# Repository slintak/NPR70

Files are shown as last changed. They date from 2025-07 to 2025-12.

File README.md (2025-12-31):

# NPR70 — New Packet Radio for 70 cm Band

A complete open-source hardware and firmware project for a modern IP packet
radio modem operating on the 70 cm amateur band (420–450 MHz).  Compatible with
the NPR [New Packet Radio](https://hackaday.io/project/164092-npr-new-packet-radio),
but with custom hardware and improvements for easier DIY assembly.

## What is NPR70?

**NPR70** is an open-source implementation of a New Packet Radio (NPR) modem — a
  protocol and hardware design for transmitting IP packets over UHF (70 cm)
  amateur radio, with the following goals:

- High throughput (typically 50–500 kbps gross rate)
- Reliable point-to-multipoint IP networking (TCP/IP, UDP, etc.)
- Fully open hardware and software
- Minimal latency and straightforward configuration

This project is **primarily for amateur radio operators** interested in building
and experimenting with modern digital data networks, Hamnet, telemetry, or
similar applications on the UHF band.

It is a fork/derivative of the
[original NPR project by F4HDK](https://hackaday.io/project/164092-npr-new-packet-radio),
but with new custom hardware, simplified design, and refactored/cleaned firmware.

## Who is this for?

- Licensed amateur radio operators interested in high-speed IP digital modes
- Hamnet and HSMM enthusiasts
- Anyone interested in open hardware wireless networking on UHF

## Hardware Overview

- **MCU**: STM32 microcontroller (STM32L432KCU, as in original)
- **RF Module**: NiceRF module for 70 cm UHF band  (based on SI4463)
- **Ethernet**: W5500 (SPI, 10/100 Mbps Ethernet controller)
- **Form Factor**: Two layer 69×100 mm PCB
- **Other**: 0402 SMD passives, SMA, Ethernet and USB-C connectors, etc.

The hardware is designed to be compact and affordable, with a focus on
DIY manufacturing and community development. All schematics and layout
files are in the [`pcb/`](pcb/) directory.

## Firmware Details

- Based on **MbedOS 5.6.6** (last version compatible with the original code)
- Derived from the [F4HDK NPR firmware]
  (https://github.com/f4hdk/NewPacketRadio), but refactored and cleaned up for
  different pinout
- Supports all main NPR features (TDMA master/slave, 2GFSK/4GFSK,
  point-to-multipoint IP bridging)
- Compatible with official NPR protocol and other compatible modems

## Key Features

| Feature | Details |
|---|---|
| **Protocol** | NPR (custom IP radio, NOT AX.25; true L3) |
| **Topology** | Point-to-multipoint (master + up to 7 clients), TDMA |
| **Modulation** | 2GFSK / 4GFSK, up to 500 kbps gross (see protocol docs) |
| **RF Band** | 70 cm amateur band (configurable, typically 430–440 MHz) |
| **Network** | Full IP stack, transparent bridging, works with DHCP, TCP/IP, UDP, etc. |
| **Range** | Up to 300 km line-of-sight (with suitable antennas and power) |
| **Hardware** | STM32 MCU, SI4463 radio, W5500 Ethernet, all open hardware  |
| **License** | GPL v3.0 (same as original NPR project) |

## Repository Structure

- `pcb/` – KiCAD project directory (schematic and PCB layout).
- `src/` – Firmware source code, based on MbedOS (legacy version), derived and
  adapted from the original NPR project.

## Quick Start

1. **Hardware**: Manufacture or assemble the PCB found in `pcb/`. BOM and
   assembly notes are included.
2. **Firmware**:
    - For building the code by youself, you will need Debian based system and
      installed `gcc-arm-none-eabi`.
    - Build firmware by running `make` in the `src/` directory.
    - Firmware binary is in  the `src/BUILD/NPR70.hex` file
    - Flash firmware to the STM32 MCU using an SWD programmer
      `pyocd load -t stm32l432kc BUILD/NPR70.hex`
3. **Configuration**: Adjust radio parameters (frequency, bandwidth,
   master/client mode, IP addresses) as described in the
   [original NPR documentation](https://cdn.hackaday.io/files/1640927020512128/NPR70_introduction_EN_v3.6.pdf)
4. **Connect**: Plug in Ethernet and power, connect antenna, and start experimenting

Basic settings to check (more details in the original NPR documentation):

* `display config`: show current configuration
* `set <param> <value>`: store value to the given parameter
* `save`: saves current configuration into the EEPROM
* `radio on`/`radio off`: turn RF on or off
* `reboot`: reboot the FW

You have to set your callsign, frequency and modulation. Rest of the parameters
is up to you and your setup.

```
set callsign AB1CDE
set frequency 434.200
set modulation 22
```

## Documentation and References

- [Original NPR project by F4HDK](https://hackaday.io/project/164092-npr-new-packet-radio)
- [Official NPR documentation (PDFs, guides, protocol)](https://cdn.hackaday.io/files/1640927020512128/NPR70_introduction_EN_v3.6.pdf)
- [Project homepage and build log (in Czech)](https://uart.cz/2773/the-new-packet-radio/)

## License

This project is released under the **GPL v3.0 license**, same as the original
NPR project by F4HDK. See [LICENSE](LICENSE) for full details.

## Contributing

Contributions are welcome! You can:

- Submit hardware design improvements (new PCB revisions, bugfixes)
- Help with firmware optimization, porting to newer MbedOS versions, or adding
  features
- Share test results, deployment reports, and real-world feedback
- Translate documentation

For major changes, please open an issue first to discuss what you would like to
change.

If you have questions or suggestions, feel free to open an
[issue](https://github.com/slintak/NPR70/issues).

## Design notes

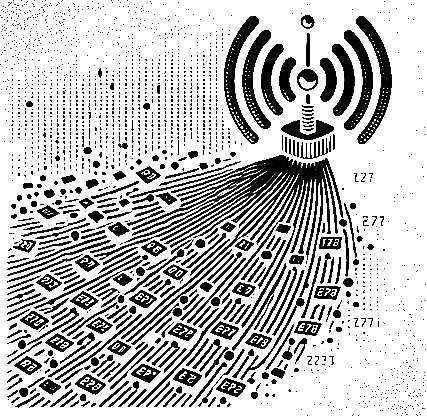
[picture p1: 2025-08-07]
pcb/imgs/art_packets_antenna.png

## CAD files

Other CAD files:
tools/radio_config_generation_2/radio_config_generation.obj

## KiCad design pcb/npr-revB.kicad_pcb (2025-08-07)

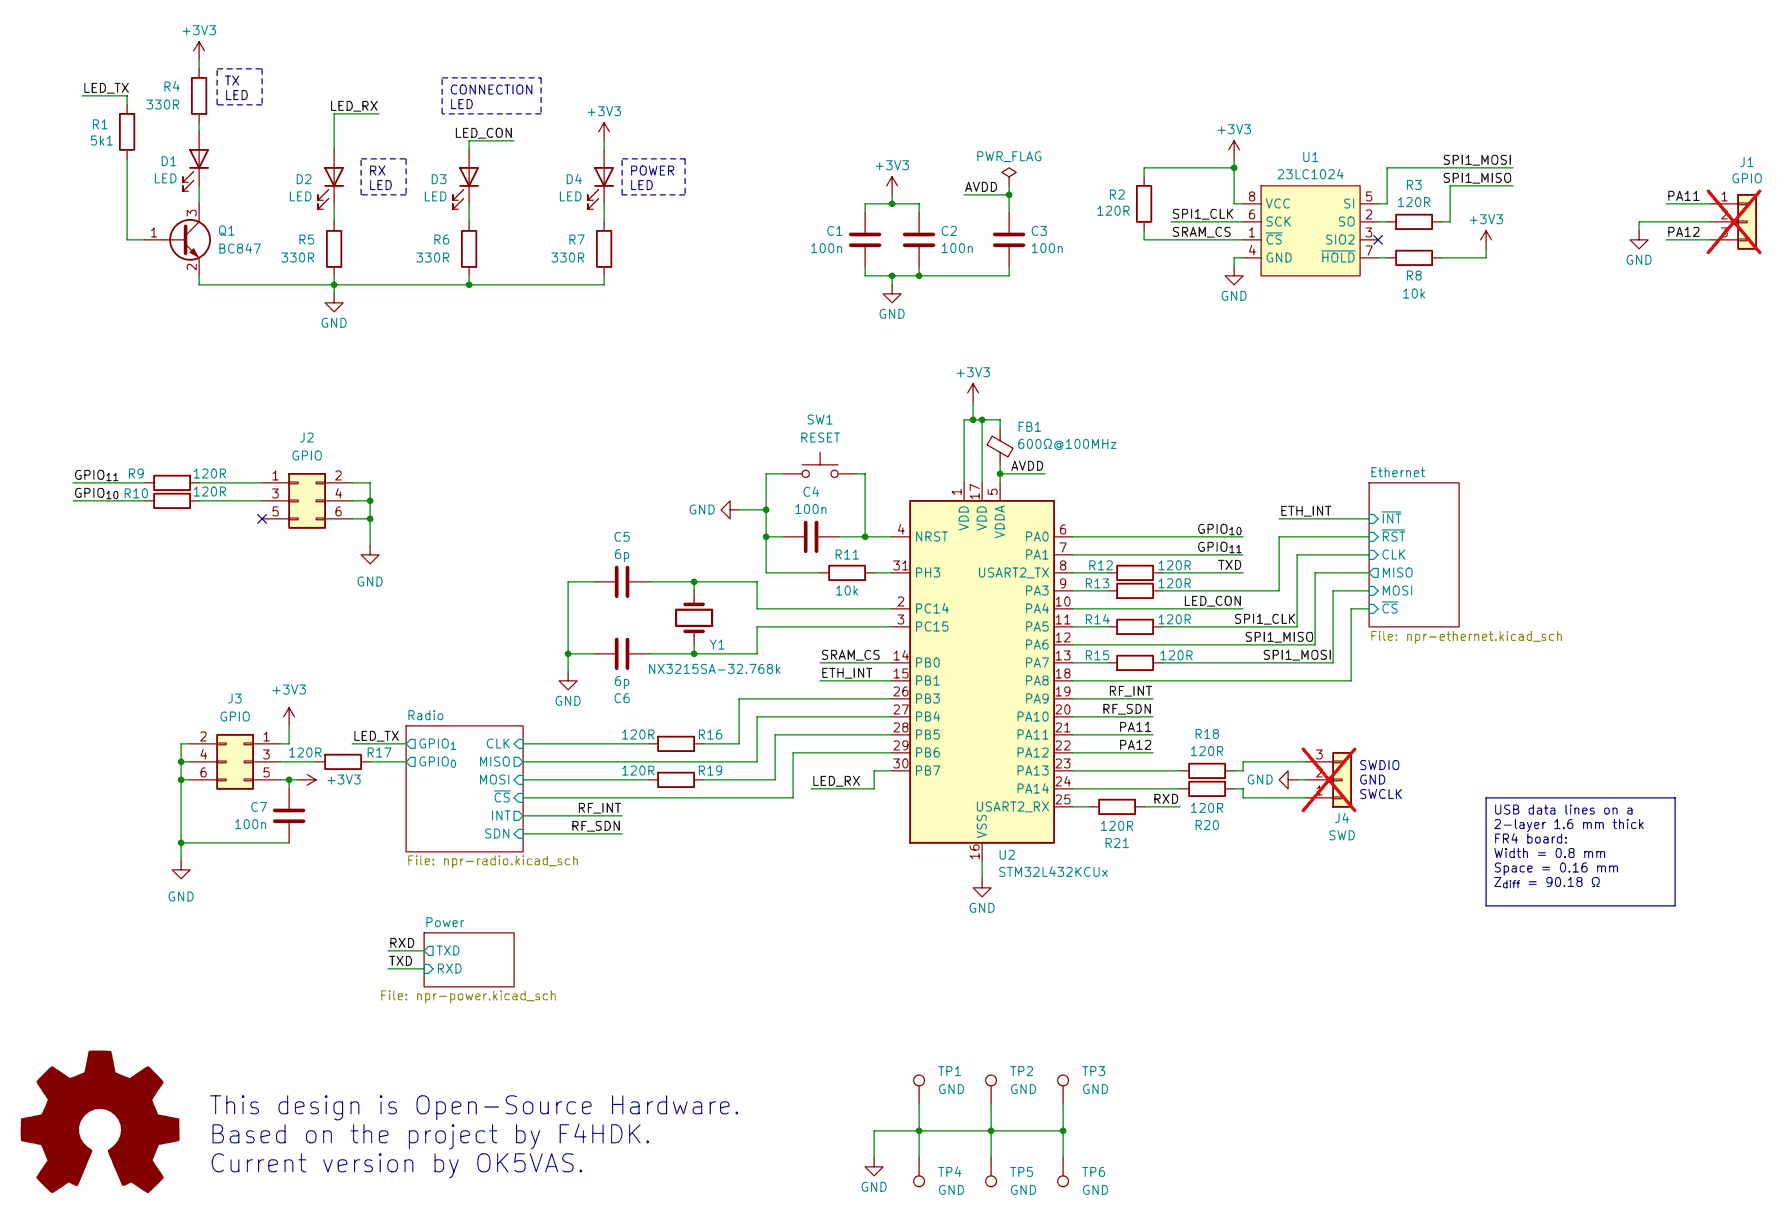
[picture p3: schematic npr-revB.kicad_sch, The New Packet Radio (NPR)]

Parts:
C1, C2, C3, C4, C7: 100n; C_0402_1005Metric; LCSC C1525
C5, C6: 6p; C_0402_1005Metric; LCSC C700515
D1, D2, D3, D4: LED; LED_0603_1608Metric; LCSC C2286
FB1: 600Ω@100MHz; L_0603_1608Metric; LCSC C19330
J1: GPIO; PinHeader_1x03_P2.54mm_Vertical; not fitted
J2, J3: GPIO; IDC-Header_2x03_P2.54mm_Horizontal; LCSC C34945
J4: SWD; PinHeader_1x03_P2.54mm_Vertical; not fitted
Q1: BC847; SOT-23; LCSC C57668
R1: 5k1; R_0402_1005Metric; LCSC C25905
R2, R3, R9, R10, R12, R13, R14, R15, R16, R17, R18, R19, R20, R21: 120R; R_0402_1005Metric; LCSC C25079
R4, R5, R6, R7: 330R; R_0402_1005Metric; LCSC C12246
R8, R11: 10k; R_0402_1005Metric; LCSC C25744
SW1: RESET; SW_SPST_CK_RS282G05A3; LCSC C483808
TP1, TP2, TP3, TP4, TP5, TP6: GND; TestPoint_Pad_D3.0mm
U1: 23LC1024; SOP-8_3.9x4.9mm_P1.27mm; LCSC C48388
U2: STM32L432KCUx; QFN-32-1EP_5x5mm_P0.5mm_EP3.45x3.45mm; LCSC C1337280
Y1: NX3215SA-32.768k; Crystal_SMD_3215-2Pin_3.2x1.5mm; LCSC C156244

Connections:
+3V3: C1.1, C2.1, C7.1, D4.2 (A), FB1.1, J3.1, J3.5, R2.2, R4.1, R8.2, U1.8 (VCC), U2.1 (VDD), U2.17 (VDD); also elsewhere on the board
/AVDD: C3.1, FB1.2, U2.5 (VDDA)
/ETH_INT: U2.15 (PB1); also elsewhere on the board
/Ethernet/~CS: U2.18 (PA8); also elsewhere on the board
/Ethernet/~RST: R13.1; also elsewhere on the board
/GPIO_{10}: R10.1, U2.6 (PA0)
/GPIO_{11}: R9.1, U2.7 (PA1)
/LED_CON: D3.2 (A), U2.10 (PA4)
/LED_RX: D2.2 (A), U2.30 (PB7)
/LED_TX: R1.2; also elsewhere on the board
/PA11: J1.1, U2.21 (PA11)
/PA12: J1.3, U2.22 (PA12)
/RF_INT: U2.19 (PA9); also elsewhere on the board
/RF_SDN: U2.20 (PA10); also elsewhere on the board
/RXD: R21.2; also elsewhere on the board
/Radio/CLK: R16.2; also elsewhere on the board
/Radio/GPIO_{0}: R17.1; also elsewhere on the board
/Radio/MISO: U2.27 (PB4); also elsewhere on the board
/Radio/MOSI: R19.2; also elsewhere on the board
/Radio/~CS: U2.29 (PB6); also elsewhere on the board
/SPI1_CLK: R14.1, U1.6 (SCK); also elsewhere on the board
/SPI1_MISO: R3.1, U2.12 (PA6); also elsewhere on the board
/SPI1_MOSI: R15.1, U1.5 (SI); also elsewhere on the board
/SRAM_CS: R2.1, U1.1 (~CS), U2.14 (PB0)
/TXD: R12.2; also elsewhere on the board
GND: C1.2, C2.2, C3.2, C4.1, C5.1, C6.1, C7.2, J1.2, J2.2, J2.4, J2.6, J3.2, J3.4, J3.6, J4.2, Q1.2 (E), R5.2, R6.2, R7.2, R11.1, SW1.1, TP1.1, TP2.1, TP3.1, TP4.1, TP5.1, TP6.1, U1.4 (GND), U2.16 (VSS), U2.32 (VSS), U2.33 (VSS); also elsewhere on the board
unnamed: D1.2 (A), R4.2
unnamed: D1.1 (K), Q1.3 (C)
unnamed: D2.1 (K), R5.1
unnamed: D3.1 (K), R6.1
unnamed: D4.1 (K), R7.1
unnamed: J2.1, R9.2
unnamed: J2.3, R10.2
unnamed: J3.3, R17.2
unnamed: J4.1, R20.2
unnamed: J4.3, R18.2
unnamed: Q1.1 (B), R1.1
unnamed: R3.2, U1.2 (SO)
unnamed: R8.1, U1.7 (~HOLD)
unnamed: C4.2, SW1.2, U2.4 (NRST)
unnamed: R12.1, U2.8 (USART2_TX)
unnamed: R13.2, U2.9 (PA3)
unnamed: R14.2, U2.11 (PA5)
unnamed: R15.2, U2.13 (PA7)
unnamed: R18.1, U2.23 (PA13)
unnamed: R20.1, U2.24 (PA14)
unnamed: R21.1, U2.25 (USART2_RX)
unnamed: R16.1, U2.26 (PB3)
unnamed: R19.1, U2.28 (PB5)
unnamed: C5.2, U2.2 (PC14), Y1.2
unnamed: C6.2, U2.3 (PC15), Y1.1
unnamed: R11.2, U2.31 (PH3)

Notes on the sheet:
This design is Open-Source Hardware. Based on the project by F4HDK. Current version by OK5VAS.
SWDIO GND SWCLK
RX LED
CONNECTION LED
TX LED
POWER LED
USB data lines on a 2-layer 1.6 mm thick FR4 board: Width = 0.8 mm Space = 0.16 mm Z_{diff} = 90.18 Ω

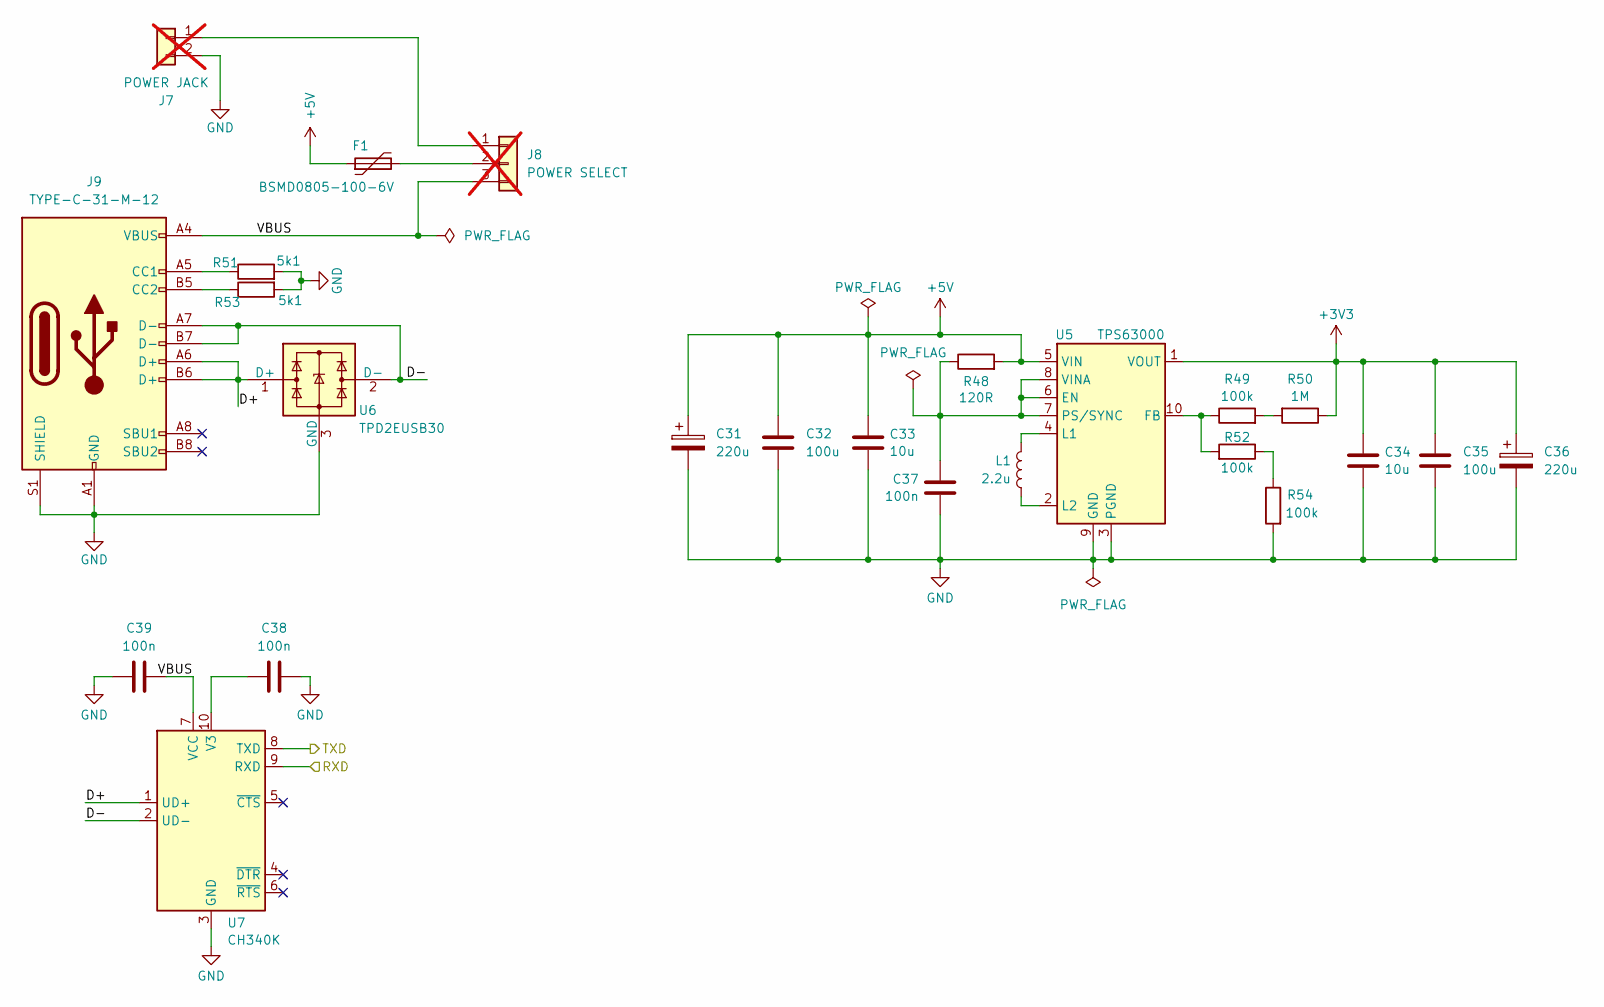
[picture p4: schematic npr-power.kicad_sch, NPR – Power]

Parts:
C31, C36: 220u; CP_Elec_6.3x5.4; LCSC C2833309
C32, C35: 100u; C_1206_3216Metric; LCSC C15008
C33, C34: 10u; C_0603_1608Metric; LCSC C19702
C37, C38, C39: 100n; C_0402_1005Metric; LCSC C1525
F1: BSMD0805-100-6V; Fuse_0805_2012Metric; LCSC C883112
J7: POWER JACK; PinHeader_1x02_P2.54mm_Vertical; not fitted
J8: POWER SELECT; PinHeader_1x03_P2.54mm_Vertical; not fitted
J9: TYPE-C-31-M-12; USB_C_Receptacle_HRO_TYPE-C-31-M-12; LCSC C165948
L1: 2.2u; L_Taiyo-Yuden_MD-3030; LCSC C5159665
R48: 120R; R_0402_1005Metric; LCSC C25079
R49, R52, R54: 100k; R_0402_1005Metric; LCSC C25741
R50: 1M; R_0402_1005Metric; LCSC C26083
R51, R53: 5k1; R_0402_1005Metric; LCSC C25905
U5: TPS63000; Texas_DRC0010J_ThermalVias; LCSC C24966
U6: TPD2EUSB30; Texas_DRT-3; LCSC C97502
U7: CH340K; SSOP-10-1EP_3.9x4.9mm_P1mm_EP2.1x3.3mm; LCSC C18208922

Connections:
+3V3: C34.1, C35.1, C36.1, R50.1, U5.1 (VOUT); also elsewhere on the board
+5V: C31.1, C32.1, C33.1, F1.1, R48.2, U5.5 (VIN); also elsewhere on the board
/Power/D+: J9.A6 (D+), J9.B6 (D+), U6.1 (D+), U7.1 (UD+)
/Power/D-: J9.A7 (D-), J9.B7 (D-), U6.2 (D-), U7.2 (UD-)
/Power/VBUS: C39.2, J8.3, J9.A4 (VBUS), J9.A9 (VBUS), J9.B4 (VBUS), J9.B9 (VBUS), U7.7 (VCC)
/RXD: U7.8 (TXD); also elsewhere on the board
/TXD: U7.9 (RXD); also elsewhere on the board
GND: C31.2, C32.2, C33.2, C34.2, C35.2, C36.2, C37.2, C38.2, C39.1, J7.2, J9.A1 (GND), J9.A12 (GND), J9.B1 (GND), J9.B12 (GND), J9.S1 (SHIELD), R51.2, R53.2, R54.2, U5.3 (PGND), U5.9 (GND), U5.11 (PGND), U6.3 (GND), U7.3 (GND), U7.11 (GND); also elsewhere on the board
unnamed: J7.1, J8.1
unnamed: F1.2, J8.2
unnamed: J9.A5 (CC1), R51.1
unnamed: J9.B5 (CC2), R53.1
unnamed: R49.2, R50.2
unnamed: R52.1, R54.1
unnamed: C37.1, R48.1, U5.6 (EN), U5.7 (PS/SYNC), U5.8 (VINA)
unnamed: R49.1, R52.2, U5.10 (FB)
unnamed: L1.2, U5.4 (L1)
unnamed: L1.1, U5.2 (L2)
unnamed: C38.1, U7.10 (V3)

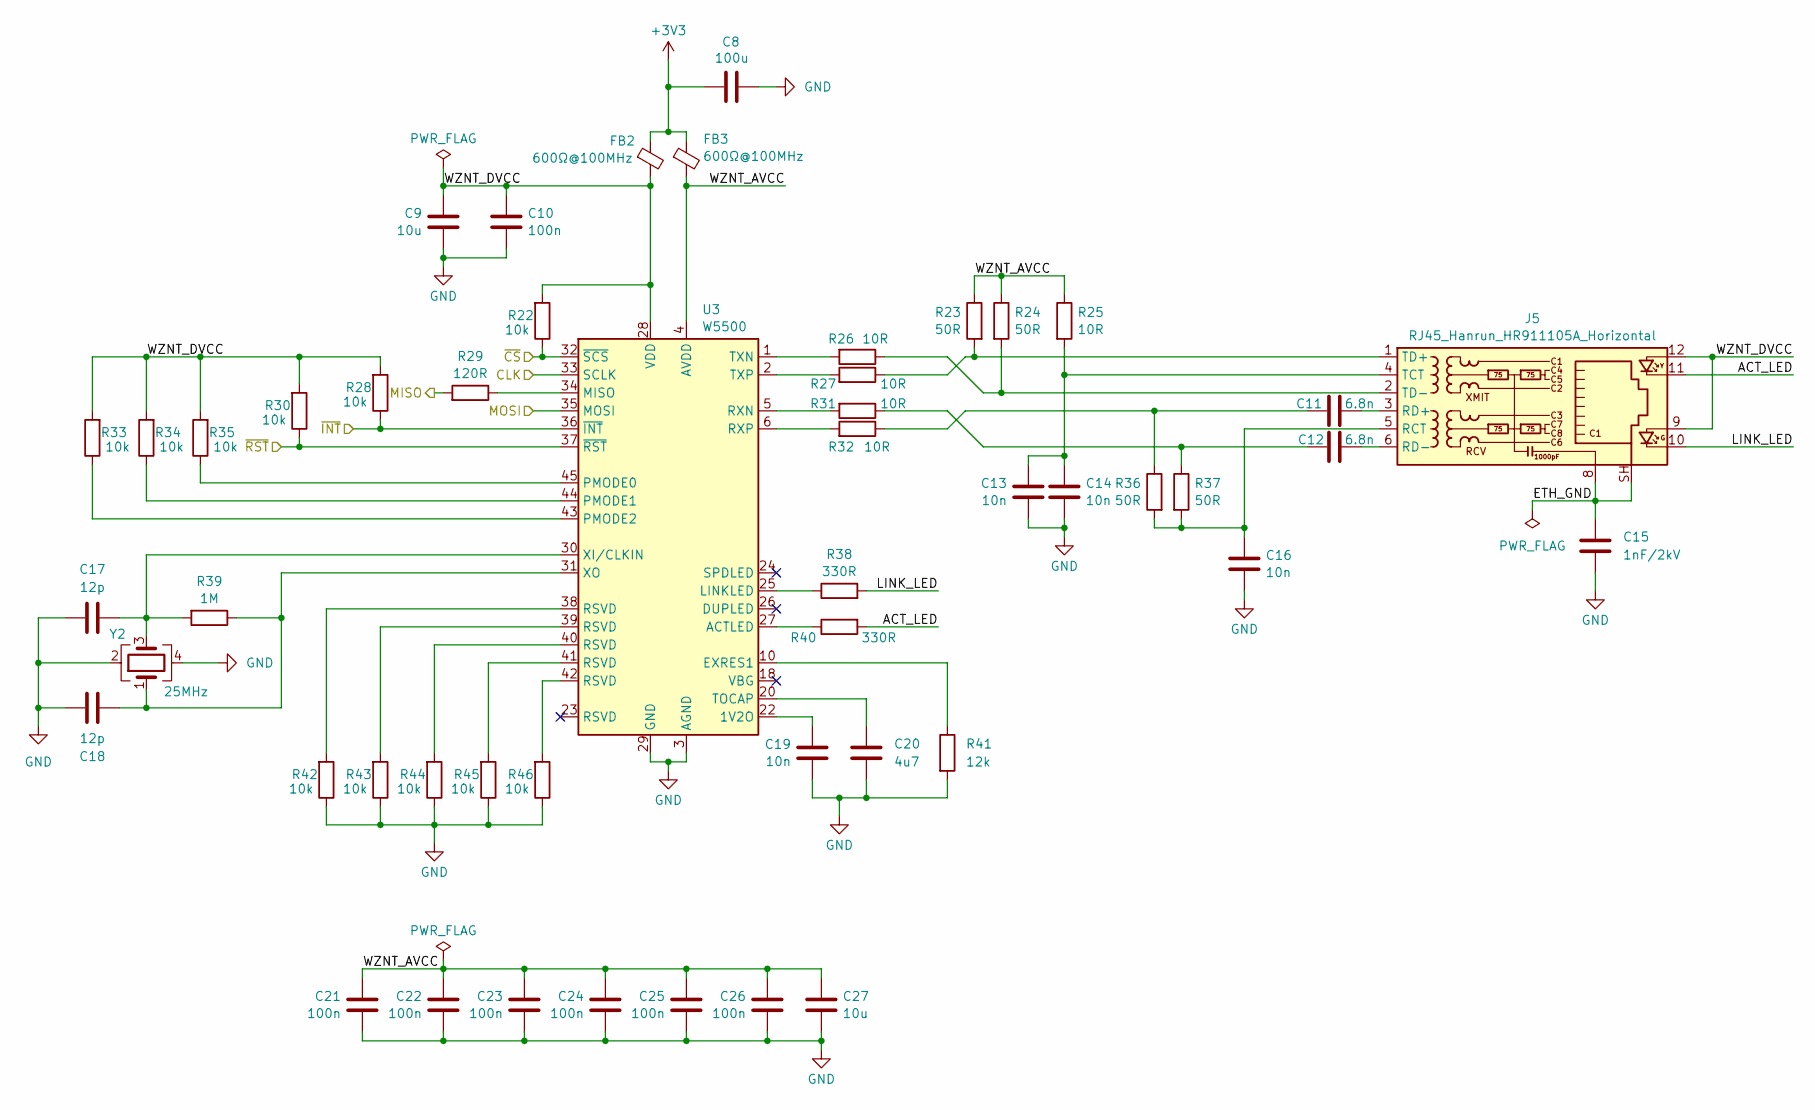
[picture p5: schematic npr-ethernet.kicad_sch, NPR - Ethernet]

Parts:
C8: 100u; C_1206_3216Metric; LCSC C15008
C9, C27: 10u; C_0402_1005Metric; LCSC C15525
C10, C21, C22, C23, C24, C25, C26: 100n; C_0402_1005Metric; LCSC C1525
C11, C12: 6.8n; C_0402_1005Metric; LCSC C93654
C13, C14, C16, C19: 10n; C_0402_1005Metric; LCSC C318577
C15: 1nF/2kV; C_1206_3216Metric; LCSC C23631
C17, C18: 12p; C_0402_1005Metric; LCSC C106201
C20: 4u7; C_0402_1005Metric; LCSC C23733
FB2, FB3: 600Ω@100MHz; L_0603_1608Metric; LCSC C19330
J5: RJ45_Hanrun_HR911105A_Horizontal; LCSC C12074
R22, R28, R30, R33, R34, R35, R42, R43, R44, R45, R46: 10k; R_0402_1005Metric; LCSC C25744
R23, R24, R36, R37: 50R; R_0402_1005Metric; LCSC C227387
R25, R26, R27, R31, R32: 10R; R_0402_1005Metric; LCSC C25139
R29: 120R; R_0402_1005Metric; LCSC C25079
R38, R40: 330R; R_0402_1005Metric; LCSC C12246
R39: 1M; R_0402_1005Metric; LCSC C26083
R41: 12k; R_0402_1005Metric; LCSC C25752
U3: W5500; LQFP-48_7x7mm_P0.5mm; LCSC C32843
Y2: 25MHz; Crystal_SMD_3225-4Pin_3.2x2.5mm; LCSC C9006

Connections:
+3V3: C8.1, FB2.1, FB3.1; also elsewhere on the board
/ETH_INT: R28.1, U3.36 (~INT); also elsewhere on the board
/Ethernet/ACT_LED: J5.11, R40.2
/Ethernet/ETH_GND: C15.1, J5.8, J5.SH
/Ethernet/LINK_LED: J5.10, R38.2
/Ethernet/WZNT_AVCC: C21.1, C22.1, C23.1, C24.1, C25.1, C26.1, C27.1, FB3.2, R23.1, R24.1, R25.1, U3.4 (AVDD), U3.8 (AVDD), U3.11 (AVDD), U3.15 (AVDD), U3.17 (AVDD), U3.21 (AVDD)
/Ethernet/WZNT_DVCC: C9.1, C10.1, FB2.2, J5.9, J5.12, R22.2, R28.2, R30.2, R33.2, R34.2, R35.2, U3.28 (VDD)
/Ethernet/~CS: R22.1, U3.32 (~SCS); also elsewhere on the board
/Ethernet/~RST: R30.1, U3.37 (~RST); also elsewhere on the board
/SPI1_CLK: U3.33 (SCLK); also elsewhere on the board
/SPI1_MISO: R29.2; also elsewhere on the board
/SPI1_MOSI: U3.35 (MOSI); also elsewhere on the board
GND: C8.2, C9.2, C10.2, C13.2, C14.2, C15.2, C16.2, C17.2, C18.2, C19.2, C20.2, C21.2, C22.2, C23.2, C24.2, C25.2, C26.2, C27.2, R41.2, R42.1, R43.1, R44.1, R45.1, R46.1, U3.3 (AGND), U3.9 (AGND), U3.14 (AGND), U3.16 (AGND), U3.19 (AGND), U3.29 (GND), U3.48 (AGND), Y2.2, Y2.4; also elsewhere on the board
unnamed: C11.2, R32.1, R36.1
unnamed: C12.2, R31.1, R37.1
unnamed: C16.1, J5.5 (RCT), R36.2, R37.2
unnamed: C11.1, J5.3 (RD+)
unnamed: C12.1, J5.6 (RD-)
unnamed: C13.1, C14.1, J5.4 (TCT), R25.2
unnamed: J5.1 (TD+), R23.2, R27.1
unnamed: J5.2 (TD-), R24.2, R26.1
unnamed: R42.2, U3.38 (RSVD)
unnamed: R43.2, U3.39 (RSVD)
unnamed: R44.2, U3.40 (RSVD)
unnamed: R45.2, U3.41 (RSVD)
unnamed: R46.2, U3.42 (RSVD)
unnamed: C19.1, U3.22 (1V2O)
unnamed: R40.1, U3.27 (ACTLED)
unnamed: R41.1, U3.10 (EXRES1)
unnamed: R38.1, U3.25 (LINKLED)
unnamed: R29.1, U3.34 (MISO)
unnamed: R35.1, U3.45 (PMODE0)
unnamed: R34.1, U3.44 (PMODE1)
unnamed: R33.1, U3.43 (PMODE2)
unnamed: R31.2, U3.5 (RXN)
unnamed: R32.2, U3.6 (RXP)
unnamed: C20.1, U3.20 (TOCAP)
unnamed: R26.2, U3.1 (TXN)
unnamed: R27.2, U3.2 (TXP)
unnamed: C17.1, R39.2, U3.30 (XI/CLKIN), Y2.3
unnamed: C18.1, R39.1, U3.31 (XO), Y2.1

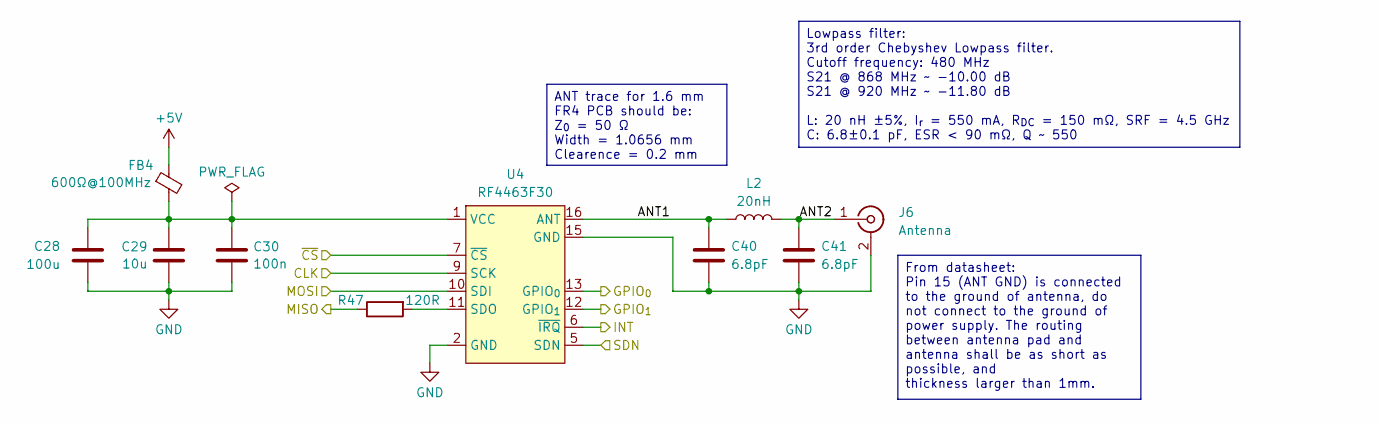
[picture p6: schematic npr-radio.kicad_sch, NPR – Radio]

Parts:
C28: 100u; C_1206_3216Metric; LCSC C15008
C29: 10u; C_0402_1005Metric; LCSC C15525
C30: 100n; C_0402_1005Metric; LCSC C1525
C40, C41: 6.8pF; C_0402_1005Metric; LCSC C88896
FB4: 600Ω@100MHz; L_0603_1608Metric; LCSC C19330
J6: Antenna; SMA_Amphenol_901-143_Horizontal; LCSC C411575
L2: 20nH; L_0603_1608Metric; LCSC C17702828
R47: 120R; R_0402_1005Metric; LCSC C25079
U4: RF4463F30; LCSC C5356658

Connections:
+5V: FB4.1; also elsewhere on the board
/LED_TX: U4.12 (GPIO_{1}); also elsewhere on the board
/RF_INT: U4.6 (~IRQ); also elsewhere on the board
/RF_SDN: U4.5 (SDN); also elsewhere on the board
/Radio/ANT1: C40.1, L2.1, U4.16 (ANT)
/Radio/ANT2: C41.1, J6.1 (In), L2.2
/Radio/CLK: U4.9 (SCK); also elsewhere on the board
/Radio/GPIO_{0}: U4.13 (GPIO_{0}); also elsewhere on the board
/Radio/MISO: R47.1; also elsewhere on the board
/Radio/MOSI: U4.10 (SDI); also elsewhere on the board
/Radio/~CS: U4.7 (~CS); also elsewhere on the board
GND: C28.2, C29.2, C30.2, C40.2, C41.2, J6.2 (Ext), U4.2 (GND), U4.8 (GND), U4.15 (GND); also elsewhere on the board
unnamed: R47.2, U4.11 (SDO)
unnamed: C28.1, C29.1, C30.1, FB4.2, U4.1 (VCC)

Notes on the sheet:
Lowpass filter: 3rd order Chebyshev Lowpass filter. Cutoff frequency: 480 MHz S21 @ 868 MHz ~ -10.00 dB S21 @ 920 MHz ~ -11.80 dB L: 20 nH ±5%, I_{r} = 550 mA, R_{DC} = 150 mΩ, SRF = 4.5 GHz C: 6.8±0.1 pF, ESR < 90 mΩ, Q ~ 550
From datasheet: Pin 15 (ANT GND) is connected to the ground of antenna, do not connect to the ground of power supply. The routing between antenna pad and antenna shall be as short as possible, and thickness larger than 1mm.
ANT trace for 1.6 mm FR4 PCB should be: Z_{0} = 50 Ω Width = 1.0656 mm Clearence = 0.2 mm

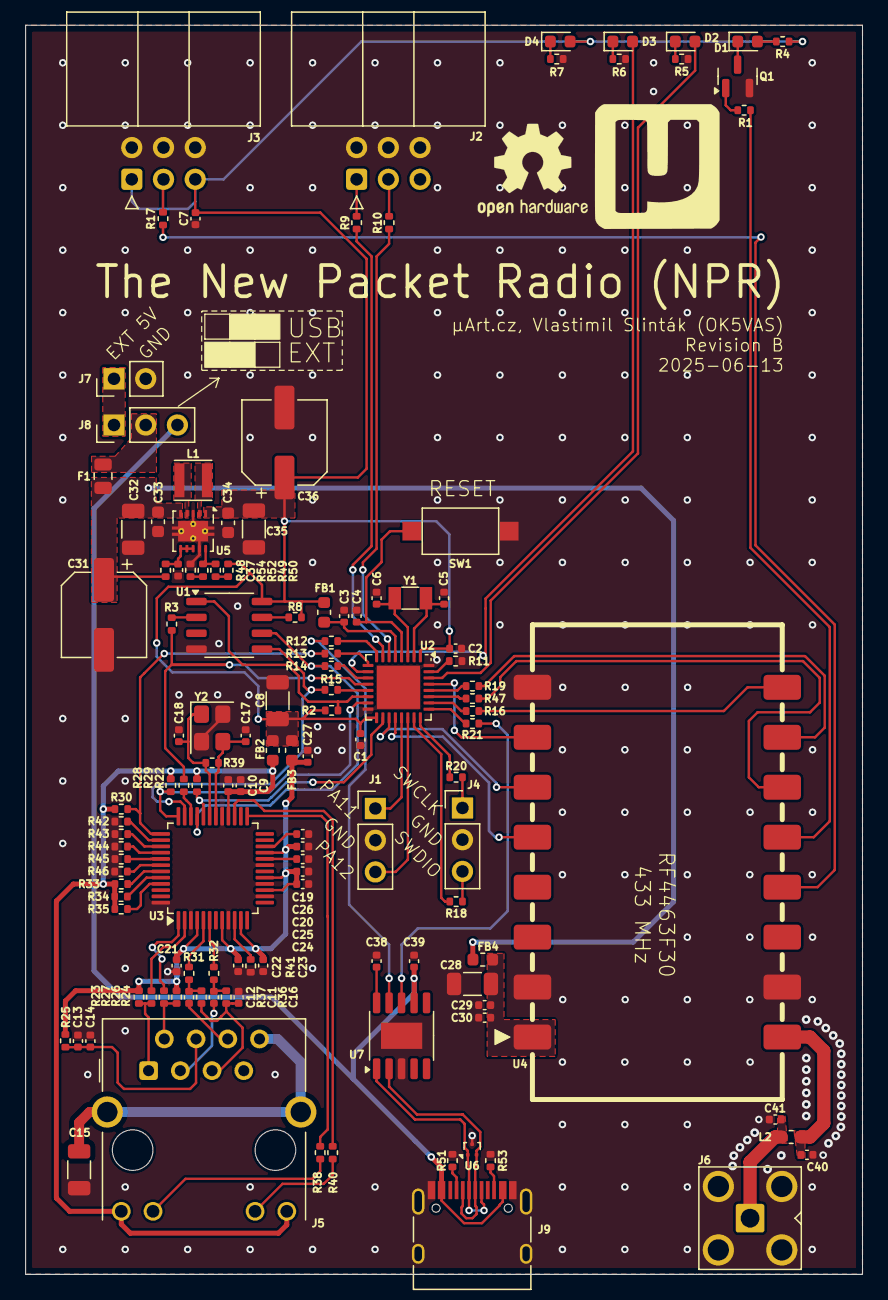
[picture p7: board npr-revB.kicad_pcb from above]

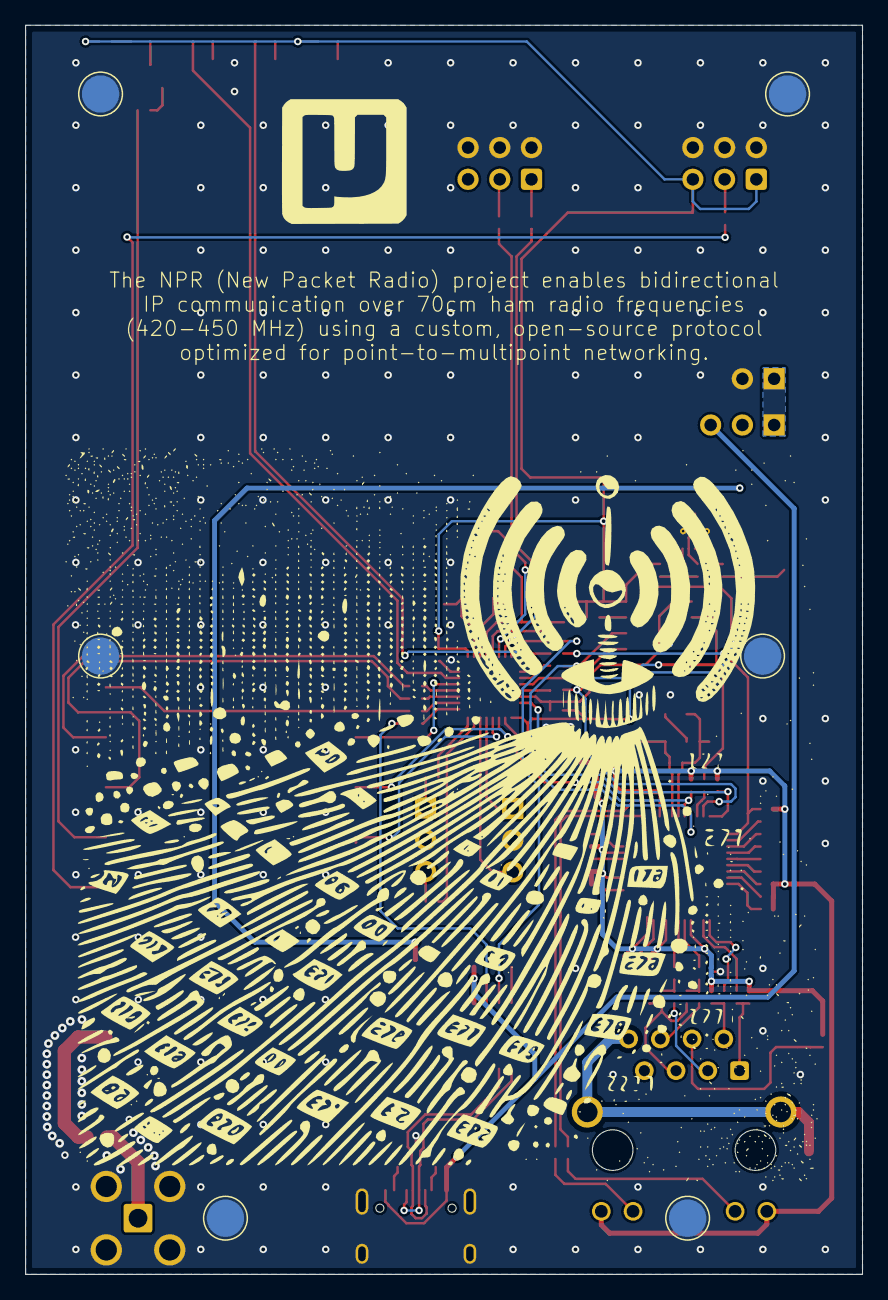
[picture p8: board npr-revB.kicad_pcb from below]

Board: 2 copper layers, 67.0 x 100.0 mm, 132 parts (6 on the bottom side), 104 nets.

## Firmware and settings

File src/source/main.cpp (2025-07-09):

// This file is part of "NPR70 modem firmware" software
// (A GMSK data modem for ham radio 430-440MHz, at several hundreds of kbps) 
// Copyright (c) 2017-2020 Guillaume F. F4HDK (amateur radio callsign)
// 
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
#include "mbed.h"
#include "W5500.h"
#include "SI4463.h"
#include "HMI_telnet.h"
//#include "Virt_Chan.h"
#include "Eth_IPv4.h"
#include "DHCP_ARP.h"
#include "global_variables.h"
#include "L1L2_radio.h"
#include "TDMA.h"
#include "signaling.h"
#include "config_flash.h"
#include "SPI_F4HDK.h"

#include "ext_SRAM2.h"

//#define NPR_L476
//Serial pc(SERIAL_TX, SERIAL_RX); // Nucleo
//Serial pc(USBTX, USBRX); //NXP LPC1769

DigitalInOut FDD_trig_pin(PA_1);//GPIO_11
InterruptIn FDD_trig_IRQ(PA_1);//GPIO_11
DigitalOut PTT_PA_pin(PA_0);//GPIO_10

DigitalOut SI4463_SDN(PA_10);

DigitalOut LED_RX_loc(PB_7);
DigitalOut LED_connected(PA_4);

DigitalIn Int_W5500(PB_1);
DigitalOut CS1(PA_8);//CS W5500
SPI_F4HDK spi_2(PA_7, PA_6, PA_5); // mosi, miso, sclk (Wiznet+SRAM)
DigitalOut CS3(PB_0);// CS ext SRAM

InterruptIn Int_SI4463(PA_9);
DigitalOut CS2(PB_6);
SPI_F4HDK spi_1(PB_5, PB_4, PB_3); // mosi, miso, sclk (radio)

int main()
{
    wait_ms(200);
    pc.baud(115200);
    pc.printf("\r\n\r\nNPR FW %s\r\n", FW_VERSION);

    Timer slow_timer;
    int i = 1;
    int temperature_timer = 0;

    static LAN_conf_T* LAN_conf_p;
    LAN_conf_p = &LAN_conf_applied;

    static W5500_chip W5500_1;
    W5500_p1 = &W5500_1;
    W5500_1.spi_port = &spi_2;
    W5500_1.cs = &CS1;
    W5500_1.interrupt = &Int_W5500;

//#ifdef EXT_SRAM_USAGE
    static ext_SRAM_chip SPI_SRAM;
    SPI_SRAM_p = &SPI_SRAM;
    SPI_SRAM.spi_port = &spi_2;
    SPI_SRAM.cs = &CS3;
//#endif

    static SI4463_Chip SI4463_1;
    SI4463_1.spi = &spi_1;//1
    SI4463_1.cs = &CS2;//2
    SI4463_1.interrupt = &Int_SI4463;
    SI4463_1.RX_LED = &LED_RX_loc;
    SI4463_1.SDN = &SI4463_SDN;

    G_SI4463 = &SI4463_1;

    G_FDD_trig_pin = &FDD_trig_pin;
    G_FDD_trig_IRQ = &FDD_trig_IRQ;
    G_PTT_PA_pin = &PTT_PA_pin;

    reset_DHCP_table(LAN_conf_p);

    spi_2.format(8,0);
    spi_1.format(8,0);
    spi_2.frequency(20000000);
    spi_1.frequency(10000000);

    for(i=0; i<radio_addr_table_size; i++) {
        CONF_radio_addr_table_status[i] = 0;
    }

    G_FDD_trig_pin->input();
    G_PTT_PA_pin->write(0);
    LED_RX_loc = 0;
    LED_connected = 0;
    CS1=1;
    CS2=1;
    CS3=1;
    SI4463_SDN = 1;

    wait_ms(20);
    is_SRAM_ext = ext_SRAM_detect();

    LED_RX_loc = 1;
    for (i=0; i<7; i++) {
        wait_ms(200);
        LED_RX_loc = !LED_RX_loc;
        LED_connected = !LED_connected;
        SI4463_SDN = !SI4463_SDN;
    }
    LED_RX_loc = 0;
    LED_connected = 0;
    SI4463_SDN = 1;

    printf("\r\n");

    RX_FIFO_WR_point = 0;
    RX_FIFO_RD_point = 0;
    RX_FIFO_last_received = 0;

    //TXPS_FIFO->is_single = 0;
    //TXPS_FIFO->WR_point = 0;
    //TXPS_FIFO->RD_point = 0;
    //TXPS_FIFO->last_ready = 0;

    GLOBAL_timer.reset();
    GLOBAL_timer.start();
    TDMA_init_all();

    //TXPS_FIFO->last_ready = TXPS_FIFO->WR_point;
    for (i=0; i<0x2000; i++) {
        RX_FIFO_data[i] = 0;
    }

    printf("      \r\n");
    for (i=0; i<radio_addr_table_size; i++) {
        CONF_radio_addr_table_IP_begin[i] = 0; // 0 = entry not active

    }
    if (is_SRAM_ext) {
        printf("config WITH ext SRAM\r\n");
    } else {
        printf("config WITHOUT ext SRAM\r\n");
    }

    wait_ms(100);
    NFPR_config_read();

    //SI4463_print_version(G_SI4463);//!!!!
    SI4463_get_state(G_SI4463);

    i = SI4463_configure_all();
    if (i == 1) {
        HMI_printf("SI4463 configured\r\n");
    } else {
        HMI_printf("SI4463 error while configure\r\n");
        SI4463_print_version(G_SI4463);
        wait_ms(5000);
        if (serial_term_loop() == 0) {//no serial char detected
            NVIC_SystemReset(); //reboot
        }
    }
    //SI4463_print_version(G_SI4463);//!!!!

    W5500_initial_configure(W5500_p1);
    wait_ms(2);
#ifdef EXT_SRAM_USAGE
    ext_SRAM_set_mode(SPI_SRAM_p);
    wait_ms(2)
    ext_SRAM_init();
#endif
    TDMA_NULL_frame_init(70);

    SI4463_periodic_temperature_check(G_SI4463);
    Int_SI4463.fall(&SI4463_HW_interrupt);
    if (CONF_radio_default_state_ON_OFF) {
        //TDMA_init_all();
        //SI4463_radio_start();
        RADIO_on(1, 0, 1);//init state, no reconfigure, HMI output
    }
    HMI_printf("ready> ");
    slow_timer.start();

    unsigned int timer_snapshot;
    int slow_action_counter = 0;
    int signaling_counter = 0;
    //SI4463_temp_check_init();

    int telnet_counter = 0;

    while(1) {
        for (i=0; i<100; i++) {
            if ( (is_TDMA_master == 1) && (CONF_master_FDD == 2) ) {
                FDDup_RX_FIFO_dequeue();
            } else {
                radio_RX_FIFO_dequeue(W5500_p1);
            }
            Eth_RX_dequeue(W5500_p1);
            TDMA_slave_timeout();
#ifdef EXT_SRAM_USAGE
            ext_SRAM_periodic_call();
#endif
            if (is_SRAM_ext == 1) {
                ext_SRAM_periodic_call();
            }
            timer_snapshot = slow_timer.read_us();
            if (timer_snapshot > 666000) {//666000
                slow_timer.reset();
                slow_action_counter++;
                if (slow_action_counter > 2) {slow_action_counter = 0; }

                if (slow_action_counter == 0) {
                    HMI_periodic_call();
                }
                //debug_counter = 0;


                if (slow_action_counter == 1) {//every 2 sec
                    signaling_counter++;
                    if (signaling_counter >= CONF_signaling_period) {
                        signaling_periodic_call();
                        signaling_counter = 0;
                    }
                }

                if (slow_action_counter == 2) {
                    DHCP_ARP_periodic_free_table();
                    W5500_re_configure_periodic_call(W5500_p1);

                    temperature_timer++;
                    if(temperature_timer > 15) {// 15 every 30 sec
                        temperature_timer = 0;
                        G_need_temperature_check = 1;
                        SI4463_periodic_temperature_check_2();//SI4463_periodic_temperature_check(G_SI4463);
                    }
                }
            }
        }

        if (is_TDMA_master) {
            if (CONF_radio_state_ON_OFF==1) {LED_connected.write((timer_snapshot >> 19) & 1);}
            else {LED_connected.write(0);}
        } else {
            if (my_client_radio_connexion_state == 2) {
                LED_connected.write(1);
            }else{
                LED_connected.write(0);
            }
        }
        if (is_telnet_active) {

            telnet_counter++;
            if (telnet_counter>10) {
                telnet_loop(W5500_p1);
                telnet_counter = 0;
            }
        }
        serial_term_loop();

        if ( (LAN_conf_applied.DHCP_server_active == 1) && (is_TDMA_master == 0) ) {
            DHCP_server(LAN_conf_p, W5500_p1);
        }
    }
}

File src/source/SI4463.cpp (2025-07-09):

// This file is part of "NPR70 modem firmware" software
// (A GMSK data modem for ham radio 430-440MHz, at several hundreds of kbps) 
// Copyright (c) 2017-2020 Guillaume F. F4HDK (amateur radio callsign)
// 
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
#include "SI4463.h"

#include "mbed.h"
#include "global_variables.h"
#include "TDMA.h"
#include "HMI_telnet.h"
#include "L1L2_radio.h"
 
#ifdef FREQ_BAND_2M
    #include "SI4463_config_20_2m.h"
    #include "SI4463_config_11_2m.h"
    #include "SI4463_config_21_2m.h"
    #include "SI4463_config_12_2m.h"
    #include "SI4463_config_22_2m.h"
    #include "SI4463_config_13_2m.h"
    #include "SI4463_config_23_2m.h"
    #include "SI4463_config_14_2m.h"
    #include "SI4463_config_24_2m.h"
#else 
    //#include "SI4463_config_10.h"
    #include "SI4463_config_20.h"
    //#include "radio_config_Si4463_20.h"
    #include "SI4463_config_11.h"
    //#include "radio_config_Si4463_11.h"
    #include "SI4463_config_21.h"
    //#include "SI4463_config_21_GMSK.h"
    //#include "radio_config_Si4463_21.h"
    #include "SI4463_config_12.h"
    #include "SI4463_config_22.h"
    //#include "radio_config_Si4463_22.h"
    #include "SI4463_config_13.h"
    //#include "radio_config_Si4463_13.h"
    #include "SI4463_config_23.h"
    //#include "radio_config_Si4463_23.h"
    #include "SI4463_config_14.h"
    #include "SI4463_config_24.h"
    //#include "radio_config_Si4463_24.h"
#endif 

//Timeout SI4463_prepa_TX_1_call;
Timeout SI4463_prepa_TX_2_call;
Timeout SI4463_1st_TX_call;
Timeout SI4463_RX_timeout_call; //2019_04_05
//Ticker SI4463_temp_check2_call;

//TX_buffer_struct* TX_buff; //data structure currently used to TX

static unsigned char SI_trash[150];
static unsigned char TX_temp_rframe[384];
static unsigned char* TX_frame_to_send;
static unsigned char TX_in_progress = 0;
static unsigned char TX_test_inprogress = 0;
//int TX_frame_pointer;

// Low level functions & drivers
void SI4463_send_command(SI4463_Chip* SI4463, unsigned char* data, int size) {
    unsigned char loc_RX[30];
    SI4463->cs->write(0);
    SI4463->spi->transfer_2(data, size, loc_RX, size);
    SI4463->cs->write(1);
    wait_us(1); 
}
 
int SI4463_CTS_read_answer(SI4463_Chip* SI4463, unsigned char* data, int size, int timeout) {
    unsigned char loc_RX[10];
    unsigned char loc_TX[10];
    int answer;
    int loops = 0;
    loc_TX[0] = 0x44;
    loops = 0;
    SI4463->cs->write(0);
    SI4463->spi->transfer_2(loc_TX, 2, loc_RX, 2);
    while ((loc_RX[1] != 0xFF) && (loops < timeout)) {
        SI4463->cs->write(1);
        wait_us(20);
        SI4463->cs->write(0);
        SI4463->spi->transfer_2(loc_TX, 2, loc_RX, 2);
        loops++;
    }
    if (size > 0) {
        SI4463->spi->transfer_2(loc_TX, size, data, size);
    }
    SI4463->cs->write(1);
    wait_us(1);
    if (loops >= timeout) {
        answer = 0; 
    } else {
        answer =1;
    }
    //printf (" loc answer:%i ", answer);
    return answer;
}

//** Higher level functions ***

// configures using RADIO_CONFIGURATION_DATA_ARRAY

//int SI4463_configure_from_10(SI4463_Chip* SI4463) {
//    unsigned char radio_config_data_10[1400] = RADIO_CONFIGURATION_DATA_ARRAY_10;//22
//    CONF_TDMA_frame_duration = 939000;
//    CONF_TDMA_slot_duration = 53400;
//    CONF_reduced_TDMA_slot_duration = 20400; 
//    CONF_TDMA_slot_margin = 300;
//    CONF_TR_margain = 1300; 
//    CONF_TA_margain = 2000;
//    CONF_preamble_duration_for_decide = 3100; //1090
//    CONF_long_preamble_duration_for_TA = 3833;//1420
//    CONF_byte_duration = 143;
//    CONF_preamble_TX_long = 22;
//    CONF_preamble_TX_short = 16;
//    CONF_Tx_rframe_timeout = 30;
//    CONF_radio_timeout_small = 10000000;//10sec
//    CONF_signaling_period = 1;
//    return SI4463_configure_from_h (SI4463, radio_config_data_10);
//}

int SI4463_configure_from_20(SI4463_Chip* SI4463) {
    unsigned char radio_config_data_20[1250] = RADIO_CONFIGURATION_DATA_ARRAY_20;//22
    //unsigned char radio_config_data_20[1400] = RADIO_CONFIGURATION_DATA_ARRAY;
    CONF_TDMA_frame_duration = 560000;
    CONF_TDMA_slot_duration = 31600;
    CONF_reduced_TDMA_slot_duration = 12700; 
    CONF_TDMA_slot_margin = 300;
    CONF_TR_margain = 1300; 
    CONF_TA_margain = 2000;
    CONF_preamble_duration_for_decide = 2670; //1090
    CONF_long_preamble_duration_for_TA = 3751;//1420
    CONF_byte_duration = 80;
    CONF_preamble_TX_long = 20;
    CONF_preamble_TX_short = 16;
    CONF_Tx_rframe_timeout = 120;//8sec
    CONF_radio_timeout = 60000000;
    CONF_radio_timeout_small = 10000000;//10sec previously 20
    CONF_signaling_period = 2;//4 sec
    return SI4463_configure_from_h (SI4463, radio_config_data_20);
}

int SI4463_configure_from_11(SI4463_Chip* SI4463) {
    unsigned char radio_config_data_11[1250] = RADIO_CONFIGURATION_DATA_ARRAY_11;//22
    //unsigned char radio_config_data_11[1400] = RADIO_CONFIGURATION_DATA_ARRAY;//22
    CONF_TDMA_frame_duration = 537000;
    CONF_TDMA_slot_duration = 30250;
    CONF_reduced_TDMA_slot_duration = 11700; 
    CONF_TDMA_slot_margin = 300;
    CONF_TR_margain = 1300; 
    CONF_TA_margain = 2000;
    CONF_preamble_duration_for_decide = 1650; //1090
    CONF_long_preamble_duration_for_TA = 2473;//2292
    CONF_byte_duration = 80;
    CONF_preamble_TX_long = 25;
    CONF_preamble_TX_short = 16;
    CONF_Tx_rframe_timeout = 120;//8sec
    CONF_radio_timeout = 60000000;
    CONF_radio_timeout_small = 10000000;//10sec previously 20
    CONF_signaling_period = 2;//4sec
    return SI4463_configure_from_h (SI4463, radio_config_data_11);
}

int SI4463_configure_from_21(SI4463_Chip* SI4463) {
    unsigned char radio_config_data_21[1250] = RADIO_CONFIGURATION_DATA_ARRAY_21;//22
    //unsigned char radio_config_data_21[1400] = RADIO_CONFIGURATION_DATA_ARRAY;//22
    CONF_TDMA_frame_duration = 294500;
    CONF_TDMA_slot_duration = 16300;
    CONF_reduced_TDMA_slot_duration = 7050; 
    CONF_TDMA_slot_margin = 300;
    CONF_TR_margain = 1300; 
    CONF_TA_margain = 2000;
    CONF_preamble_duration_for_decide = 1550; //1090
    CONF_long_preamble_duration_for_TA = 2370;//1420
    CONF_byte_duration = 30;
    CONF_preamble_TX_long = 25;
    CONF_preamble_TX_short = 16;
    CONF_Tx_rframe_timeout = 90;//6 sec
    CONF_radio_timeout = 60000000;
    CONF_radio_timeout_small = 5000000;//5sec previously 10sec
    CONF_signaling_period = 1;//2sec
    return SI4463_configure_from_h (SI4463, radio_config_data_21);
}
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

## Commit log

2025-03-11 Initial commit with the original FW
    This FW for the New Packet Radio project was taken from the Hackaday
    project https://hackaday.io/project/164092-npr-new-packet-radio
    The source code is original without any modifications, ver. 2020_06_29.
    [radio_config_generation.obj]
2025-03-15 Refactor SPI extension: use inheritance instead of modifying MbedOS files
2025-03-15 Fixed most of the compilers warnings, more refactoring needed
    [L1L2_radio.cpp, SI4463.cpp]
2025-03-15 Updated pinout for the new PCB version
2025-07-09 Use TRNG for random numbers instead of analog input pin.
2025-08-07 Moved source code to the `src/` subdirectory
    [radio_config_generation.obj]
2025-08-07 Added KiCAD project for the NPR revision B PCB
    [npr-ethernet.kicad_sch, npr-power.kicad_sch, npr-radio.kicad_sch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]

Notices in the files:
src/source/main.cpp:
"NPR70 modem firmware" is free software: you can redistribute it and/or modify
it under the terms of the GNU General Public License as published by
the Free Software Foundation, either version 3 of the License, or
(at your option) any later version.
